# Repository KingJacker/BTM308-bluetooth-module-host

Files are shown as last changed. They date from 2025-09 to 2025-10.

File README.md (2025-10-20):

#  Host Board for BTM308 Bluetooth Audio Receiver

This is a carrier board for the BTM308 Bluetooth audio module.

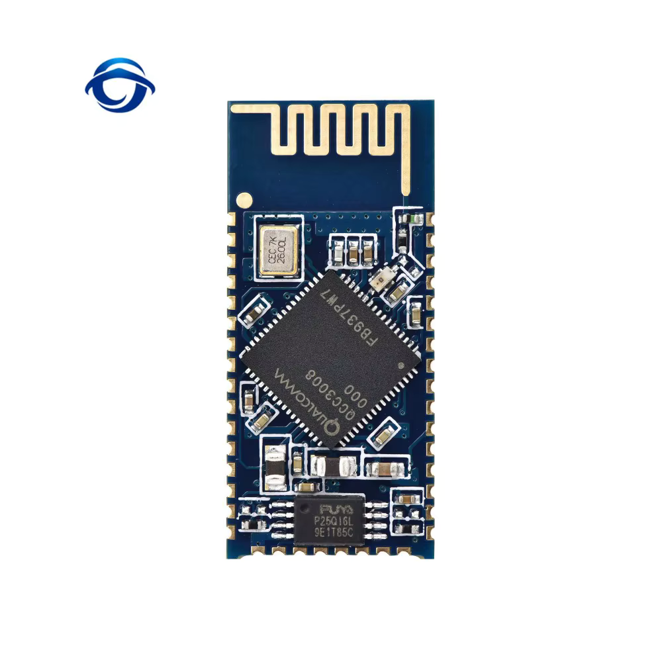
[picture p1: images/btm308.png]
BTM308-module


## Schematic

### BTM308

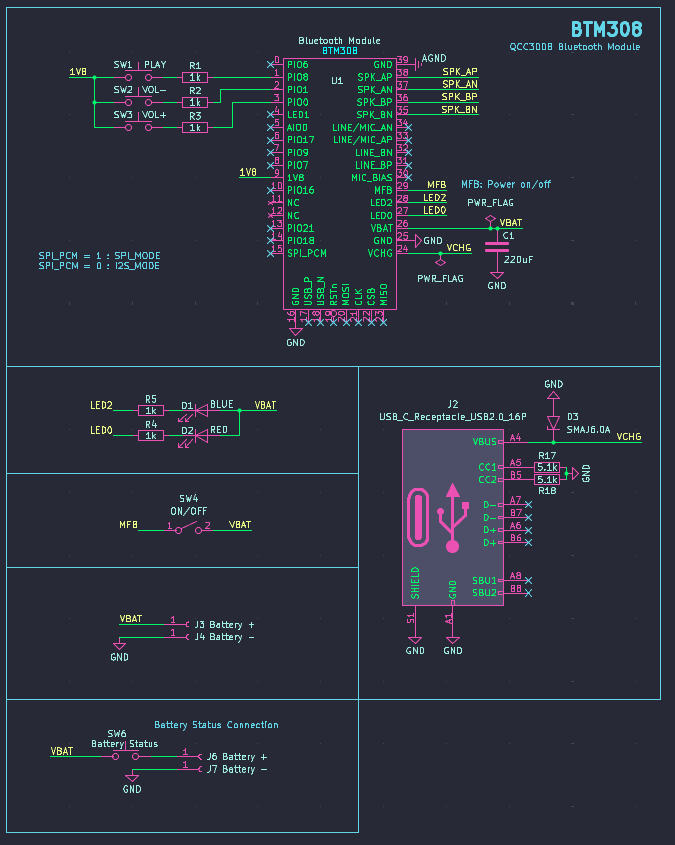
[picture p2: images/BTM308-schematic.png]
BTM308-schematic


### Differential OP-AMP (OPA1678)

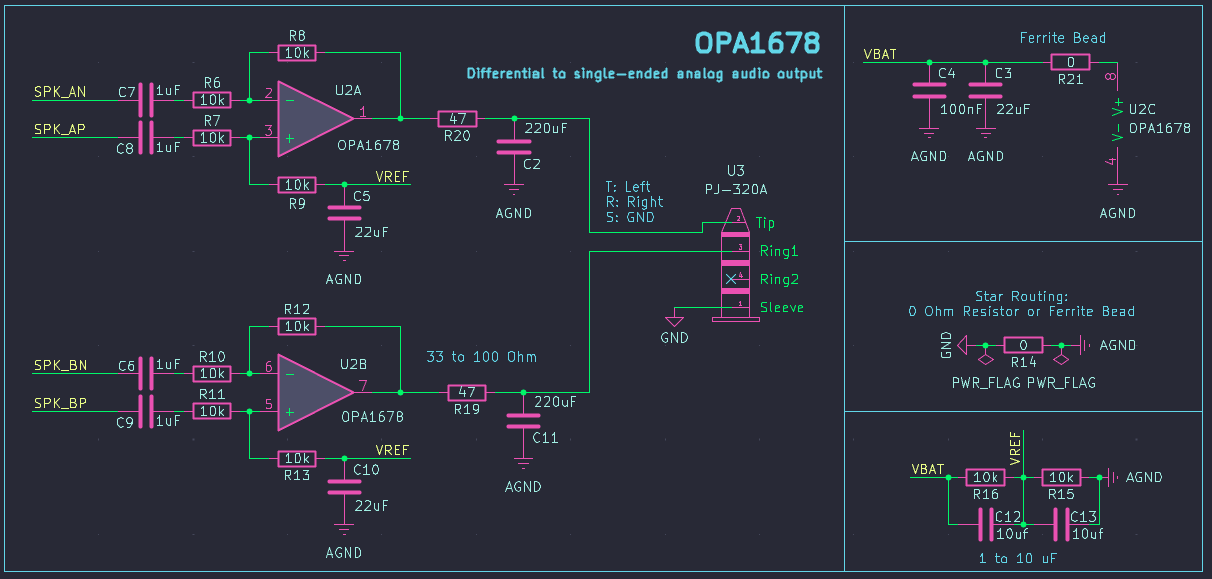
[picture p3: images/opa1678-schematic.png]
opa1678-schematic


### Board to Board Interface

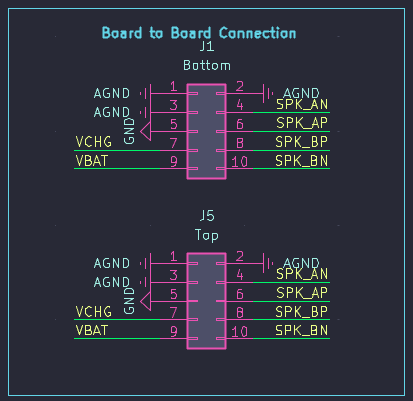
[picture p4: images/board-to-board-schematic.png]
board-to-board-schematic


## Layout

| Top | Inner 1 | Inner 2 | Bottom |
|---|---|---|---|
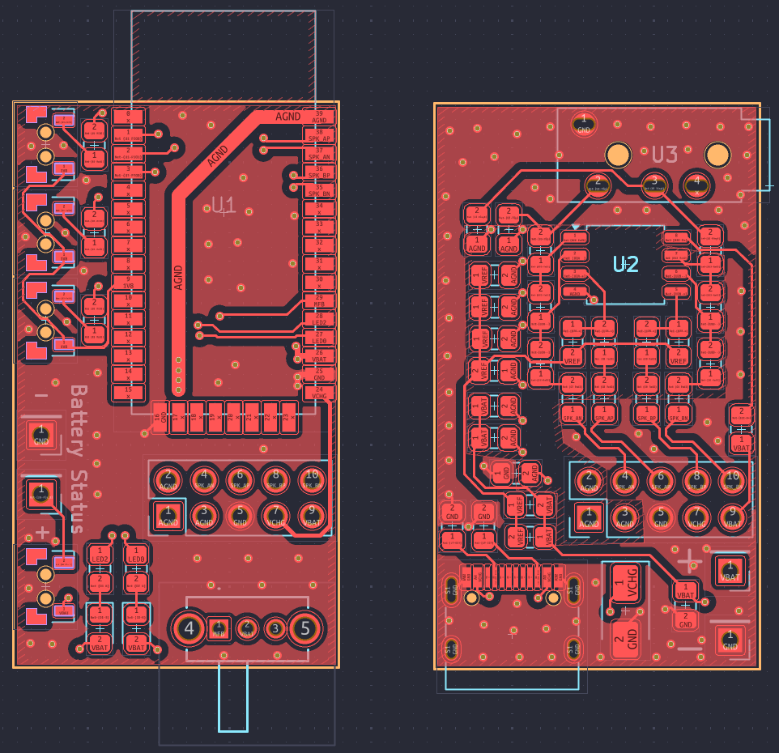
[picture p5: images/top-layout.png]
top-layout
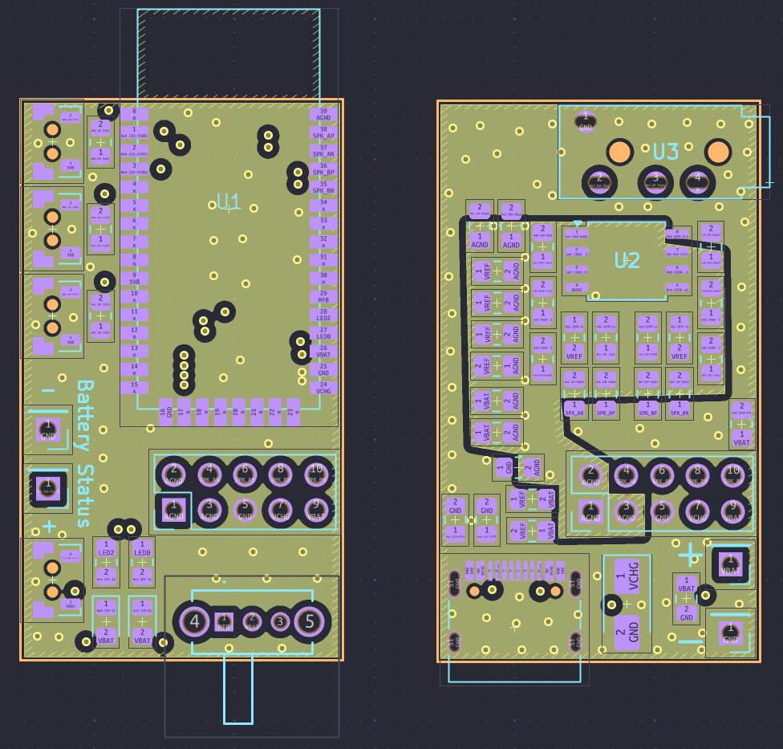
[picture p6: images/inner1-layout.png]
inner1-layout
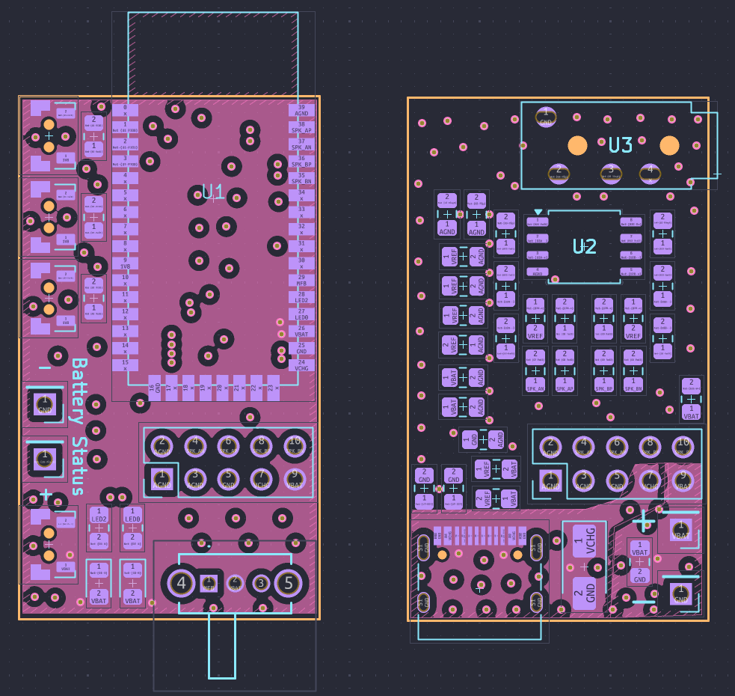
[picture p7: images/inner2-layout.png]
inner2-layout
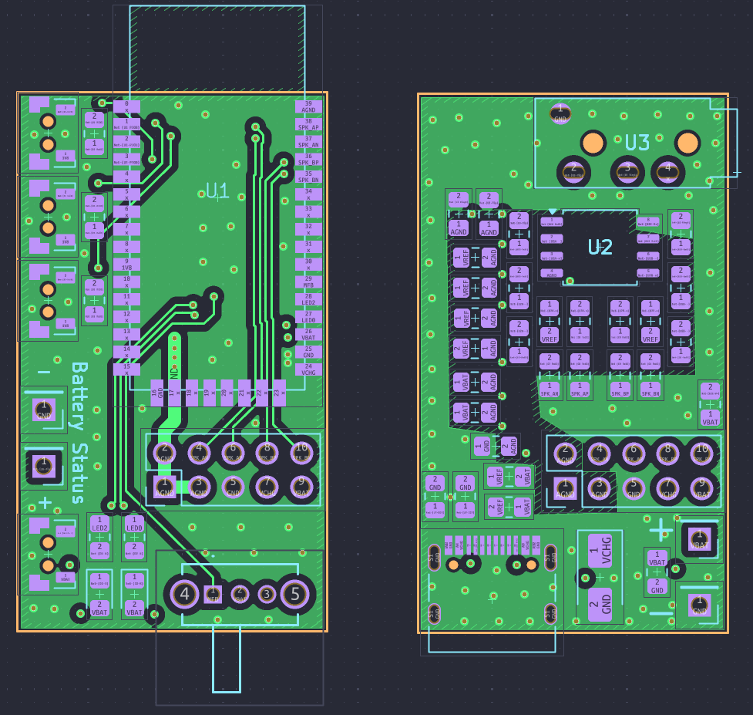
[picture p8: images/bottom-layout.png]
bottom-layout
|  |   |  |  |

## Assembly

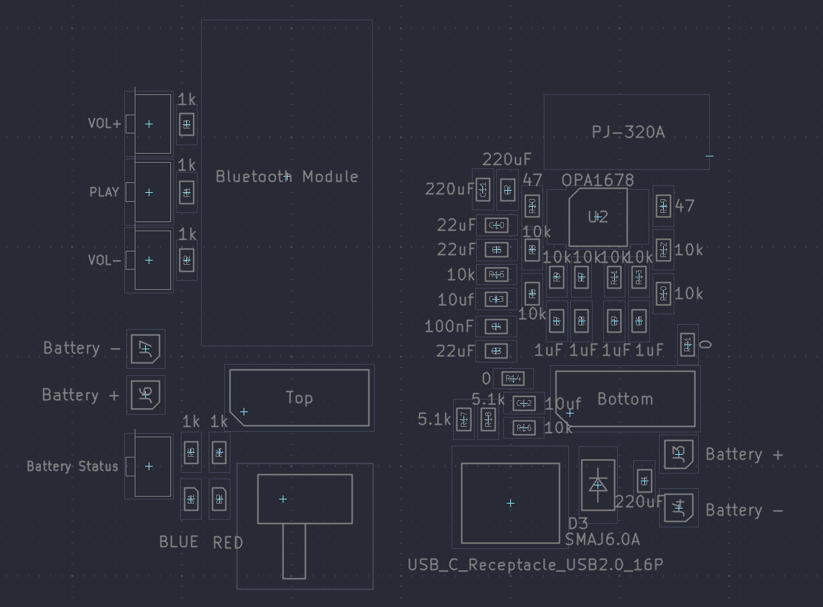
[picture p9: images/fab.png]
fab


## Bill of Materials

| Designator		| Footprint								| Qty. 	| Designation		|
| --- 				| --- 									| ---	| --- 				|
| C4				| C_0805_2012Metric						| 1		| 100nF				|
| C8,C6,C7,C9		| C_0805_2012Metric						| 4		| 1uF				|
| C12,C13			| C_0805_2012Metric						| 2		| 10uf				|
| C5,C3,C10			| C_0805_2012Metric						| 3		| 22uF				|
| C11,C1,C2			| C_0805_2012Metric						| 3		| 220uF				|
| D1				| LED_0805_2012Metric					| 1		| BLUE				|
| D2				| LED_0805_2012Metric					| 1		| RED				|
| D3				| D_SMA									| 1		| SMAJ6.0A			|
| J1				| PinHeader_2x05_P2.54mm_Vertical		| 1		| Bottom			|
| J5				| PinHeader_2x05_P2.54mm_Vertical		| 1		| Top				|
| J2				| USB_C_Receptacle_HRO_TYPE-C-31-M-12	| 1		| USB_C_Receptacle_USB2.0_16P |
| R14,R21			| R_0805_2012Metric						| 2		| 0R / Ferrite Bead	|
| R2,R5,R1,R4,R3	| R_0805_2012Metric 					| 5		| 1k				|
| R17,R18			| R_0805_2012Metric 					| 2		| 5.1k				|
| R16,R9,R6,R7,R13,R10,R11,R15,R8,R12 | R_0805_2012Metric 	| 10	| 10k				|
| R20,R19			| R_0805_2012Metric 					| 2		| 47				|
| SW6,SW1,SW2,SW3	| TST-A002_0.6MM_BOSS					| 4		| Battery Status, PLAY, VOL+/-	|
| SW4				| SLW8645745ARAND						| 1		| ON/OFF			|
| U1				| BTM308								| 1		| Bluetooth Module	|
| U2				| SOIC-8_5.3x5.3mm_P1.27mm				| 1		| OPA1678 OP-AMP |
| U3				| PJ-320A								| 1		| PJ-320A Audio |

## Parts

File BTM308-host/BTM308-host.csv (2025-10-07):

Id | Designator | Footprint | Quantity | Designation | Supplier and ref
1 | SW6 | TST-A002_0.6MM_BOSS | 1 | Battery Status
2 | J1 | PinHeader_2x05_P2.54mm_Vertical | 1 | Bottom
3 | C5,C3,C10 | C_0805_2012Metric_Pad1.18x1.45mm_HandSolder | 3 | 22uF
4 | R20,R19 | R_0805_2012Metric_Pad1.20x1.40mm_HandSolder | 2 | 47
5 | R16,R9,R6,R7,R13,R10,R11,R15,R8,R12 | R_0805_2012Metric_Pad1.20x1.40mm_HandSolder | 10 | 10k
6 | U1 | BTM308 | 1 | Bluetooth Module
7 | R2,R5,R1,R4,R3 | R_0805_2012Metric_Pad1.20x1.40mm_HandSolder | 5 | 1k
8 | C4 | C_0805_2012Metric_Pad1.18x1.45mm_HandSolder | 1 | 100nF
9 | R17,R18 | R_0805_2012Metric_Pad1.20x1.40mm_HandSolder | 2 | 5.1k
10 | C12,C13 | C_0805_2012Metric_Pad1.18x1.45mm_HandSolder | 2 | 10uf
11 | J7,J4 | PinHeader_1x01_P2.54mm_Vertical | 2 | Battery -
12 | D3 | D_SMA | 1 | SMAJ6.0A
13 | U2 | SOIC-8_5.3x5.3mm_P1.27mm | 1 | OPA1678
14 | SW1 | TST-A002_0.6MM_BOSS | 1 | PLAY
15 | J6,J3 | PinHeader_1x01_P2.54mm_Vertical | 2 | Battery +
16 | SW2 | TST-A002_0.6MM_BOSS | 1 | VOL-
17 | D2 | LED_0805_2012Metric_Pad1.15x1.40mm_HandSolder | 1 | RED
18 | C8,C6,C7,C9 | C_0805_2012Metric_Pad1.18x1.45mm_HandSolder | 4 | 1uF
19 | SW3 | TST-A002_0.6MM_BOSS | 1 | VOL+
20 | U3 | PJ-320A | 1 | PJ-320A
21 | C11,C1,C2 | C_0805_2012Metric_Pad1.18x1.45mm_HandSolder | 3 | 220uF
22 | R14,R21 | R_0805_2012Metric_Pad1.20x1.40mm_HandSolder | 2 | 0
23 | J5 | PinHeader_2x05_P2.54mm_Vertical | 1 | Top
24 | SW4 | SLW8645745ARAND | 1 | ON/OFF
25 | J2 | USB_C_Receptacle_HRO_TYPE-C-31-M-12 | 1 | USB_C_Receptacle_USB2.0_16P
26 | D1 | LED_0805_2012Metric_Pad1.15x1.40mm_HandSolder | 1 | BLUE

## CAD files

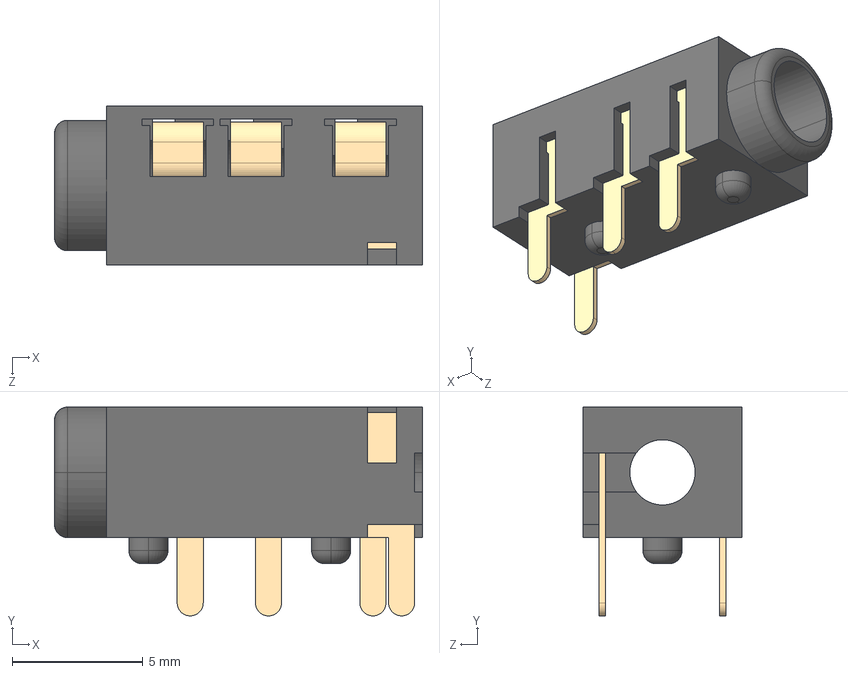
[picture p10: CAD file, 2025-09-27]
footprints/PJ-320A_KiCad_Library-main/PJ320A.STEP
14.1 x 8.00 x 6.10 mm
PJ320A蝶褲
PJ320A-Pin-A x 3
PJ320A-Pin-B

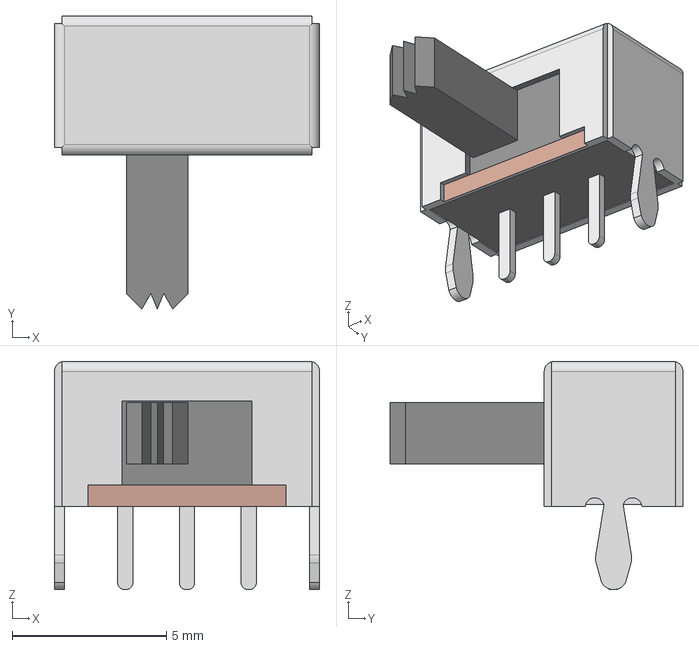
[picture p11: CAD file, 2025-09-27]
footprints/SLW-864574-5A-RA-N-D/3D/SLW-864574-5A-RA-N-D.stp
8.60 x 9.50 x 7.40 mm

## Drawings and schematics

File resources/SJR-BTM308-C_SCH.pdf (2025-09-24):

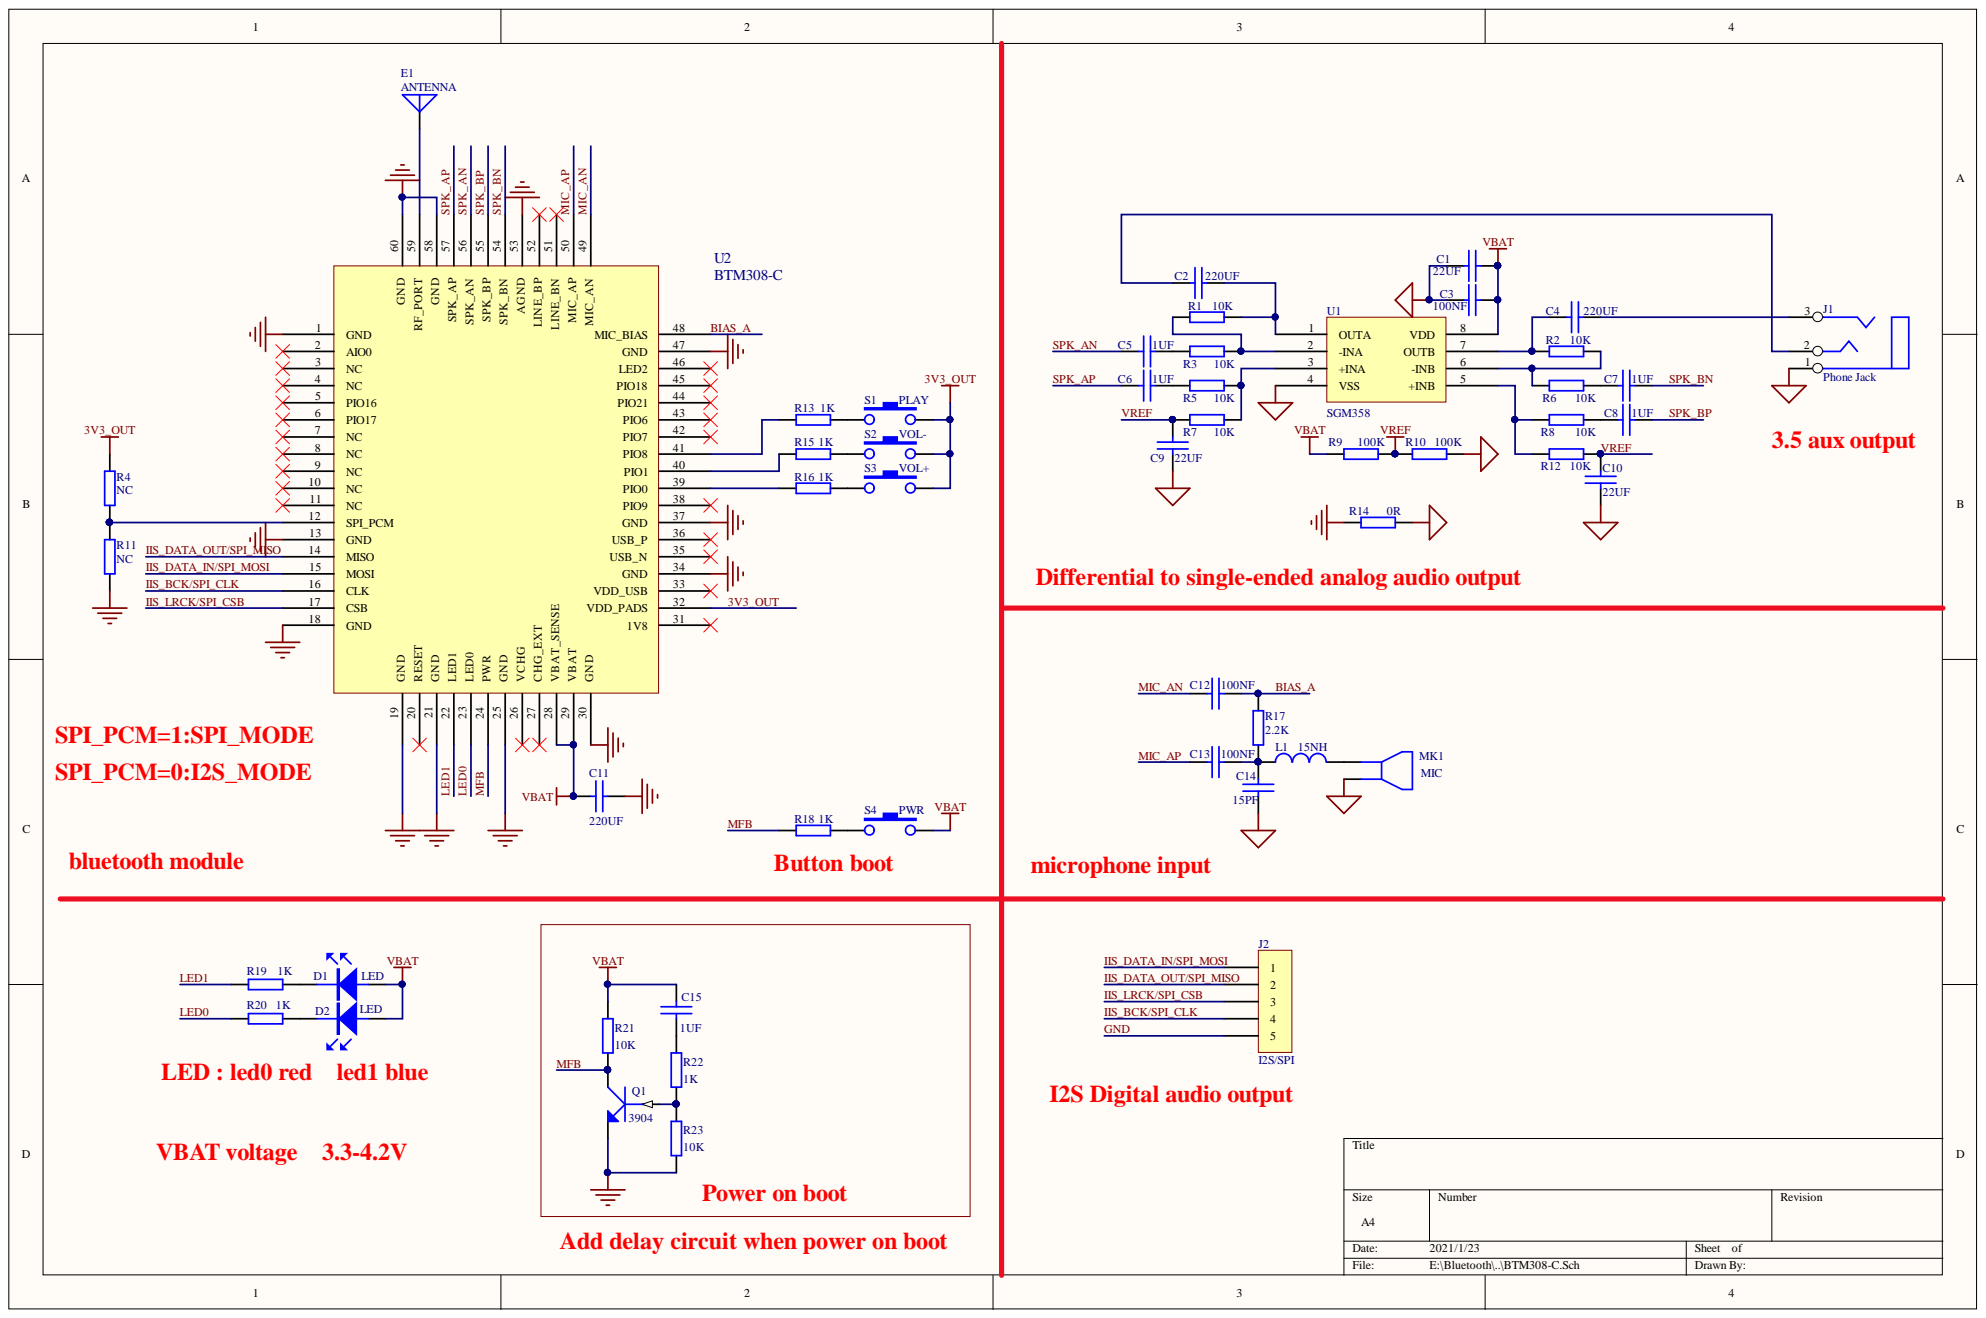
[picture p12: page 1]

Differential to single-ended analog audio output

Add delay circuit when power on boot

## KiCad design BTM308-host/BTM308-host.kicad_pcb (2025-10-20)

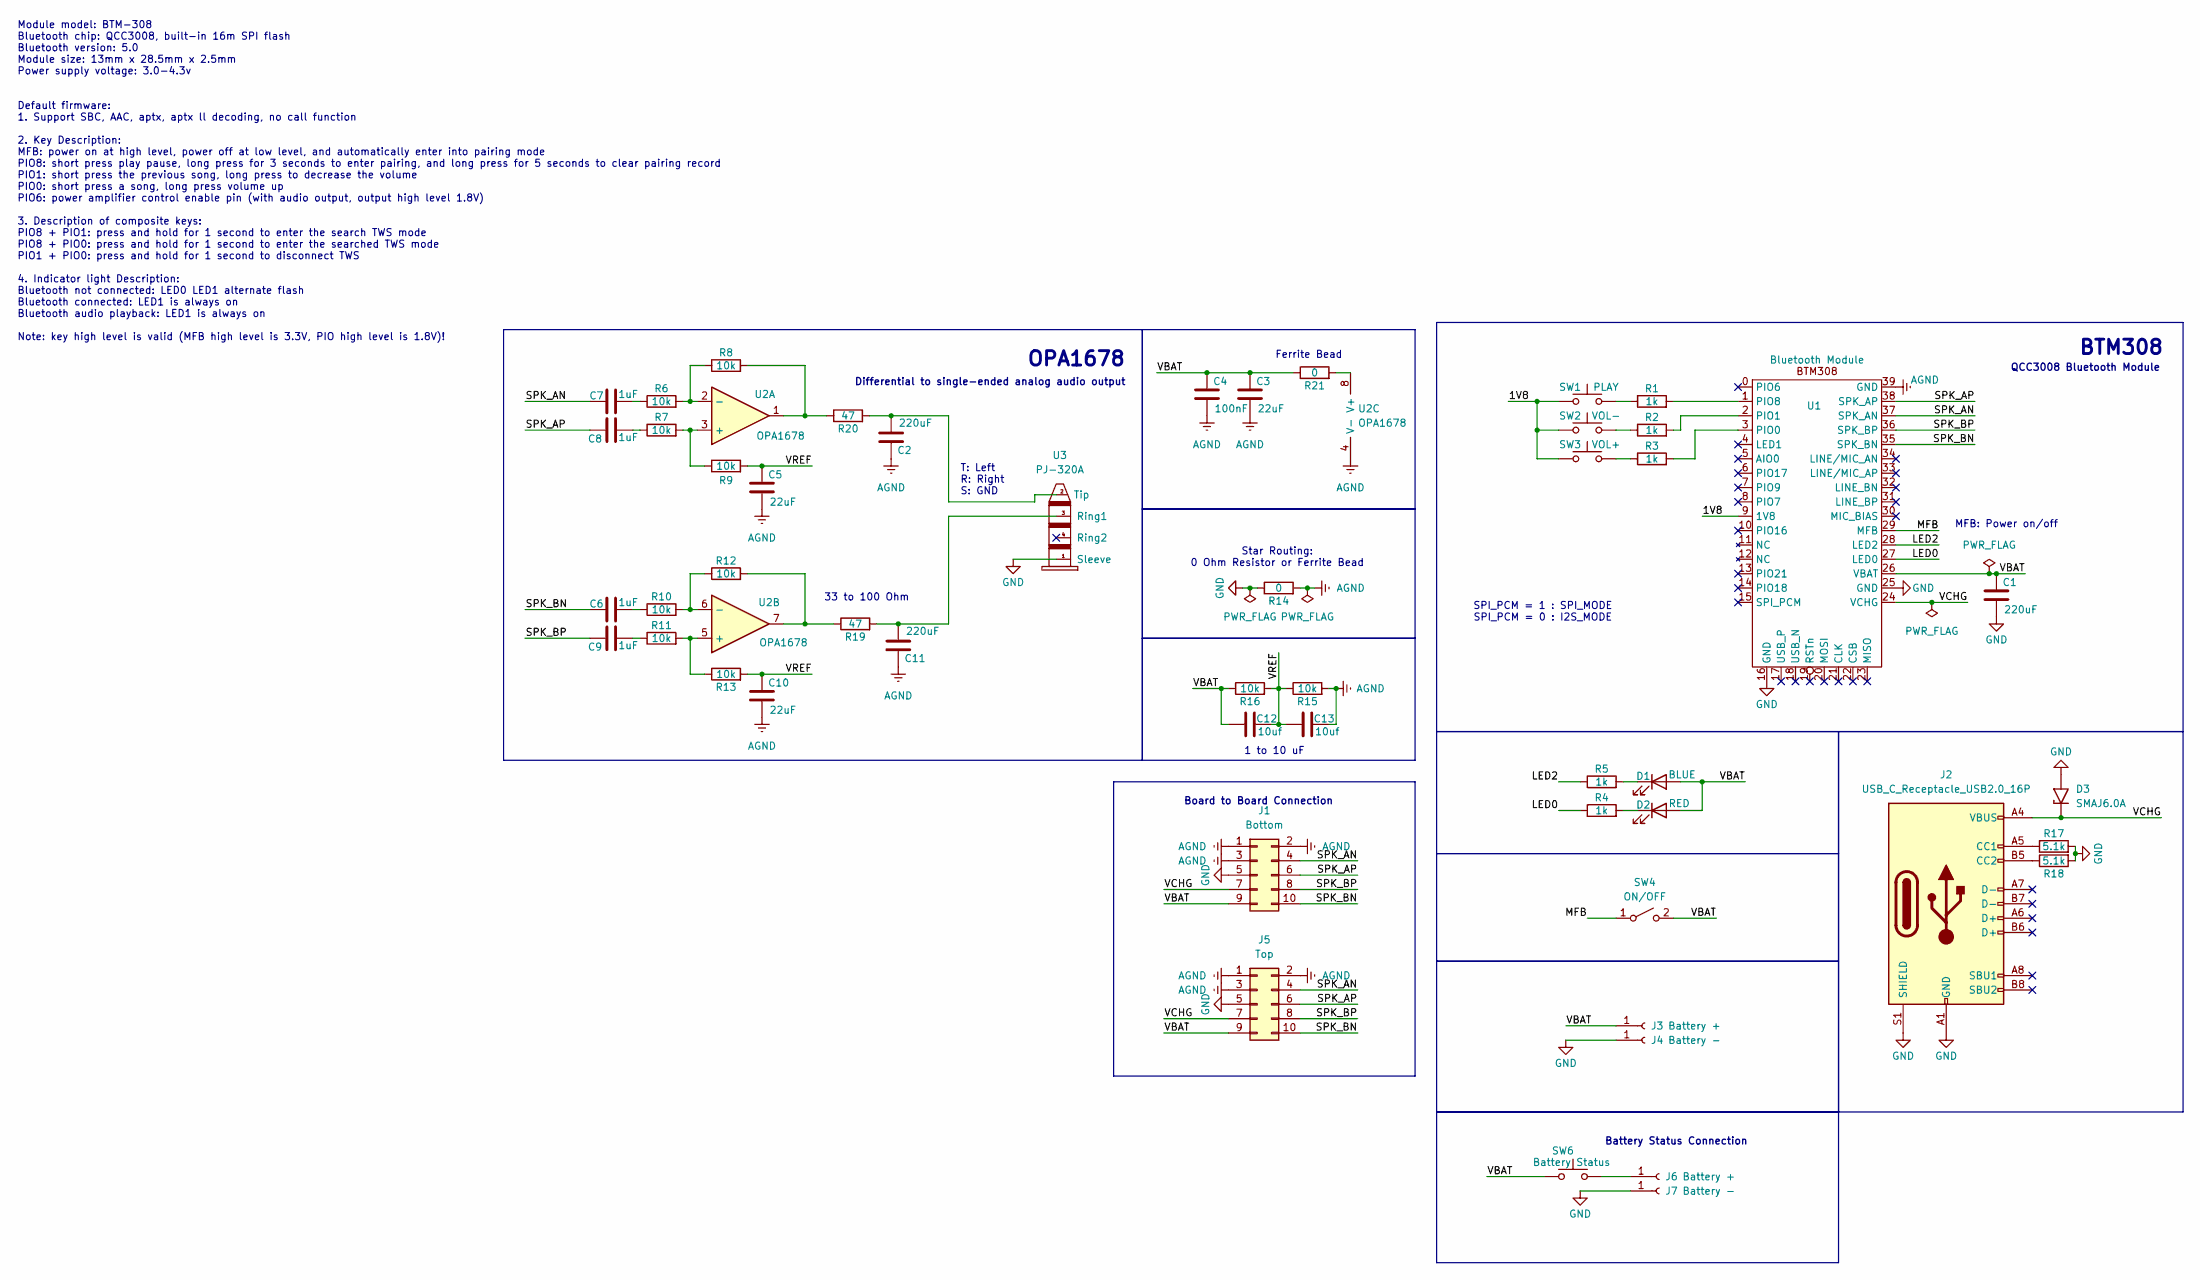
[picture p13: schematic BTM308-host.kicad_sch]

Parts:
C1, C2, C11: 220uF; C_0805_2012Metric_Pad1.18x1.45mm_HandSolder
C3, C5, C10: 22uF; C_0805_2012Metric_Pad1.18x1.45mm_HandSolder
C4: 100nF; C_0805_2012Metric_Pad1.18x1.45mm_HandSolder
C6, C7, C8, C9: 1uF; C_0805_2012Metric_Pad1.18x1.45mm_HandSolder
C12, C13: 10uf; C_0805_2012Metric_Pad1.18x1.45mm_HandSolder
D1: BLUE; LED_0805_2012Metric_Pad1.15x1.40mm_HandSolder
D2: RED; LED_0805_2012Metric_Pad1.15x1.40mm_HandSolder
D3: SMAJ6.0A; D_SMA
J1: Bottom; PinHeader_2x05_P2.54mm_Vertical
J2: USB_C_Receptacle_USB2.0_16P; USB_C_Receptacle_HRO_TYPE-C-31-M-12
J3, J6: Battery +; PinHeader_1x01_P2.54mm_Vertical
J4, J7: Battery -; PinHeader_1x01_P2.54mm_Vertical
J5: Top; PinHeader_2x05_P2.54mm_Vertical
R1, R2, R3, R4, R5: 1k; R_0805_2012Metric_Pad1.20x1.40mm_HandSolder
R6, R7, R8, R9, R10, R11, R12, R13, R15, R16: 10k; R_0805_2012Metric_Pad1.20x1.40mm_HandSolder
R14, R21: 0; R_0805_2012Metric_Pad1.20x1.40mm_HandSolder
R17, R18: 5.1k; R_0805_2012Metric_Pad1.20x1.40mm_HandSolder
R19, R20: 47; R_0805_2012Metric_Pad1.20x1.40mm_HandSolder
SW1: PLAY; TST-A002_0.6MM_BOSS
SW2: VOL-; TST-A002_0.6MM_BOSS
SW3: VOL+; TST-A002_0.6MM_BOSS
SW4: ON/OFF; SLW8645745ARAND
SW6: Battery Status; TST-A002_0.6MM_BOSS
U1: Bluetooth Module; BTM308
U2: OPA1678; SOIC-8_5.3x5.3mm_P1.27mm
U3: PJ-320A

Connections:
/1V8: SW1.1, SW2.1, SW3.1, U1.9 (1V8)
/LED0: R4.1, U1.27 (LED0)
/LED2: R5.1, U1.28 (LED2)
/MFB: SW4.1 (A), U1.29 (MFB)
/SPK_AN: C7.1, J1.4, J5.4, U1.37 (SPK_AN)
/SPK_AP: C8.1, J1.6, J5.6, U1.38 (SPK_AP)
/SPK_BN: C6.1, J1.10, J5.10, U1.35 (SPK_BN)
/SPK_BP: C9.1, J1.8, J5.8, U1.36 (SPK_BP)
/VBAT: C1.1, C3.1, C4.1, C12.2, D1.2 (A), D2.2 (A), J1.9, J3.1, J5.9, R16.1, R21.1, SW4.2 (B), SW6.1, U1.26 (VBAT)
/VCHG: D3.1 (A1), J1.7, J2.A4 (VBUS), J2.A9 (VBUS), J2.B4 (VBUS), J2.B9 (VBUS), J5.7, U1.24 (VCHG)
/VREF: C5.1, C10.1, C12.1, C13.2, R9.2, R13.2, R15.1, R16.2
AGND: C2.1, C3.2, C4.2, C5.2, C10.2, C11.1, C13.1, J1.1, J1.2, J1.3, J5.1, J5.2, J5.3, R14.2, R15.2, U1.39 (GND), U2.4 (V-)
GND: C1.2, D3.2 (A2), J1.5, J2.A1 (GND), J2.A12 (GND), J2.B1 (GND), J2.B12 (GND), J2.S1 (SHIELD), J4.1, J5.5, J7.1, R14.1, R17.2, R18.2, U1.16 (GND), U1.25 (GND), U3.1 (Sleeve)
unnamed: C6.2, R10.1
unnamed: C7.2, R6.1
unnamed: C8.2, R7.1
unnamed: C9.2, R11.1
unnamed: D1.1 (K), R5.2
unnamed: D2.1 (K), R4.2
unnamed: J2.A5 (CC1), R17.1
unnamed: J2.B5 (CC2), R18.1
unnamed: J6.1, SW6.2
unnamed: R1.1, SW1.2
unnamed: R2.1, SW2.2
unnamed: R3.1, SW3.2
unnamed: R12.2, R19.1, U2.7
unnamed: R8.2, R20.1, U2.1
unnamed: R3.2, U1.3 (PIO0)
unnamed: R2.2, U1.2 (PIO1)
unnamed: R1.2, U1.1 (PIO8)
unnamed: R7.2, R9.1, U2.3 (+)
unnamed: R6.2, R8.1, U2.2 (-)
unnamed: R11.2, R13.1, U2.5 (+)
unnamed: R10.2, R12.1, U2.6 (-)
unnamed: R21.2, U2.8 (V+)
unnamed: C11.2, R19.2, U3.3 (Ring1)
unnamed: C2.2, R20.2, U3.2 (Tip)

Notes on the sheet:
T: Left R: Right S: GND
Module model: BTM-308 Bluetooth chip: QCC3008, built-in 16m SPI flash Bluetooth version: 5.0 Module size: 13mm x 28.5mm x 2.5mm Power supply voltage: 3.0-4.3v Default firmware: 1. Support SBC, AAC, aptx, aptx ll decoding, no call function 2. Key Description: MFB: power on at high level, power off a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
SPI_PCM = 1 : SPI_MODE SPI_PCM = 0 : I2S_MODE
Differential to single-ended analog audio output
Board to Board Connection
BTM308
Battery Status Connection
MFB: Power on/off
QCC3008 Bluetooth Module
33 to 100 Ohm
1 to 10 uF
OPA1678
Ferrite Bead
Star Routing: 0 Ohm Resistor or Ferrite Bead

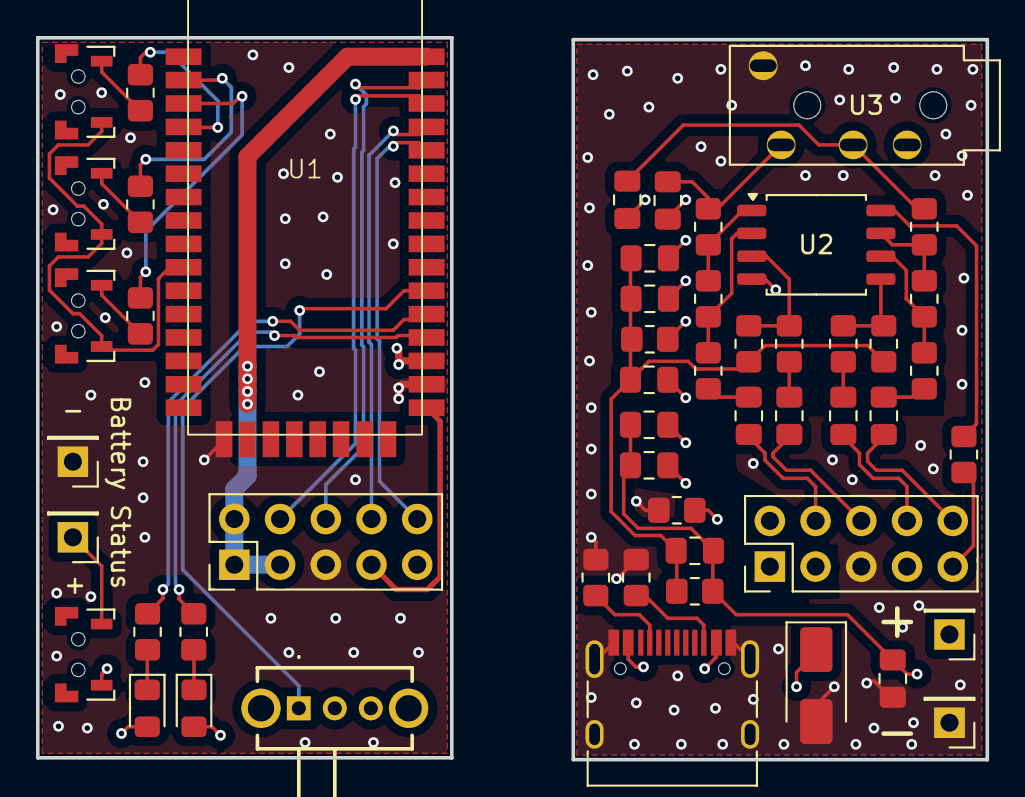
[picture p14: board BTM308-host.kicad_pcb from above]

Board: 4 copper layers, 52.8 x 40.1 mm, 52 parts (0 on the bottom side), 37 nets.

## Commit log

2025-09-26 schematic finished
    [BTM308-host.kicad_pcb, BTM308-host.kicad_sch]
2025-09-27 layout position set
    [BTM308-host.kicad_pcb, BTM308-host.kicad_sch, PJ320A.STEP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]
2025-09-27 layout done
    [BTM308-host-B_Cu.gbr, BTM308-host-B_Mask.gbr, BTM308-host-B_Paste.gbr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]
2025-10-20 added fab
    [BTM308-host.kicad_pcb]
